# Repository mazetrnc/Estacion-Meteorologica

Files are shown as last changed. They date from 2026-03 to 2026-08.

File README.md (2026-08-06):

[Monitoreo de Estación Meteorológica en ThingSpeak](https://thingspeak.mathworks.com/channels/3108150) 

<h3>Funcionamiento de la Estación Meteorológica</h3>

La estación meteorológica desarrollada utiliza una **ESP32 como unidad central de procesamiento**, encargada de adquirir, procesar y transmitir los datos obtenidos por diversos sensores ambientales. El sistema integra varios módulos conectados principalmente mediante el protocolo **I2C**, así como comunicación **UART/RS485**, lo que permite medir múltiples variables meteorológicas y ambientales en tiempo real.

En primer lugar, el sensor **BME280** mide tres variables fundamentales del clima: **temperatura, humedad relativa y presión atmosférica**. A partir de la presión también se calcula la **altitud aproximada** utilizando una presión de referencia al nivel del mar. Estos datos son obtenidos a través del bus I2C y se almacenan en variables para su posterior procesamiento.



La calidad del aire se monitorea mediante el sensor **SGP30**, que proporciona estimaciones de **CO₂ equivalente (eCO₂)** y **compuestos orgánicos volátiles totales (TVOC)**. Para mejorar la precisión de las mediciones, el código calcula la **humedad absoluta** a partir de los datos del BME280 y la envía al SGP30 como parámetro de compensación ambiental.



La **radiación ultravioleta** se mide con el sensor **LTR390**, también conectado por I2C, el cual proporciona un valor de radiación UV que puede relacionarse con el **índice UV utilizado por organismos de salud**.



Para medir la **precipitación**, se utiliza un **sensor de lluvia con cubeta basculante**, que contabiliza los pulsos generados por cada basculación causada por la acumulación de agua. El código convierte estos pulsos en **milímetros de lluvia acumulada**, permitiendo conocer la precipitación en un periodo determinado.



La **velocidad del viento** se obtiene mediante un **anemómetro con salida RS485**, que transmite los datos usando el protocolo **Modbus RTU**. Debido a que la ESP32 trabaja con niveles TTL, se emplea un **módulo conversor MAX485** para adaptar la señal RS485 a comunicación serial. El código envía una solicitud Modbus al anemómetro, recibe la respuesta, verifica su integridad mediante **CRC16**, y finalmente convierte el valor recibido en **metros por segundo (m/s)**.




Una vez que la ESP32 realiza la lectura de todos los sensores integrados (aproximadamente cada **5 segundos**), procesa la información y la expone mediante una arquitectura de red dual que combina monitoreo local e IoT en la nube simultáneamente:

1. **Servidor Web Local en Tiempo Real (Modo AP):** La ESP32 crea un punto de acceso Wi-Fi propio (`SSID: EstacionMeteo`) donde aloja un **servidor web asíncrono (`ESPAsyncWebServer`)** en la IP `192.168.4.1`. La interfaz web (almacenada en `PROGMEM` / `pagina_web.h`) consulta automáticamente el endpoint `/datos` mediante peticiones `XMLHttpRequest` en segundo plano **cada 10 segundos**. Esto actualiza los indicadores, alertas y gráficos locales de forma instantánea sin requerir recargas de página ni depender de una conexión a Internet.

2. **Publicación Remota en la Nube (Modo STA - ThingSpeak):** De forma paralela y utilizando la misma interfaz de red (`WIFI_AP_STA`), la ESP32 se conecta como cliente a un router local con salida a Internet. **Cada 5 minutos (`POST_INTERVAL_MS = 300000`)**, el microcontrolador realiza una **petición HTTP GET** al servidor de **ThingSpeak** (`api.thingspeak.com`), mapeando las lecturas a los campos del canal:

* **Field 1:** Temperatura (°C)

* **Field 2:** Humedad (%)

* **Field 3:** Presión (hPa)

* **Field 4:** Velocidad del viento (m/s)

* **Field 5:** eCO₂ (ppm)

* **Field 6:** TVOC (ppb)

* **Field 7:** Precipitación / Tasa (mm/h)

* **Field 8:** Índice UV (OMS)

Ambos modos funcionan simultáneamente y de forma totalmente independiente: si la conexión Wi-Fi a Internet falla o no está disponible, el envío a ThingSpeak se omite temporalmente sin afectar la operación del servidor web local, el cual sigue sirviendo los datos en tiempo real de forma ininterrumpida.

En conjunto, esta estación meteorológica integra sensores ambientales de precisión, protocolos de comunicación industrial y de bus (I2C y RS485/Modbus RTU), servidor web embebido y conectividad IoT híbrida para crear un sistema robusto capaz de **monitorear condiciones climáticas en tiempo real de forma local y, al mismo tiempo, publicar los resultados en una plataforma en la nube para su almacenamiento histórico y análisis remoto**.

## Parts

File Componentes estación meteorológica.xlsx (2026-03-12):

Sensor Digital BME280 I2C - Termómetro, higrómetro, barómetro | https://ja-bots.com/producto/sensor-digital-bme280-i2c/ | 22000.00
Sensor de calidad del aire SGP30 | https://www.mercadolibre.com.co/sensor-calidad-de-aire-sgp30-tvoc-eco2-i2c-gysgp30/up/MCOU3815852079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 | 29500
ANEMÓMETRO O TRASMISOR DE VELOCIDAD DEL VIENTO RS485 | https://es.aliexpress.com/item/1005005707223060.html | 102240
Módulo Conversor RS485 a TTL Uart Max485 | https://ja-bots.com/producto/modulo-conversor-rs485-a-ttl-uart-max485/ | 6000.00
Módulo sensor de luz visible UV LTR390 | https://ja-bots.com/producto/modulo-sensor-de-luz-visible-uv-ltr390/ | 47000.00
Sensor de lluvia con cubeta basculante - I2C y UART | https://es.aliexpress.com/item/1005005624682669.html?scm_id=1007.40050.354490.0&scm-url=1007.40050.354490.0 | 114938
Total sin envios |  | 321678

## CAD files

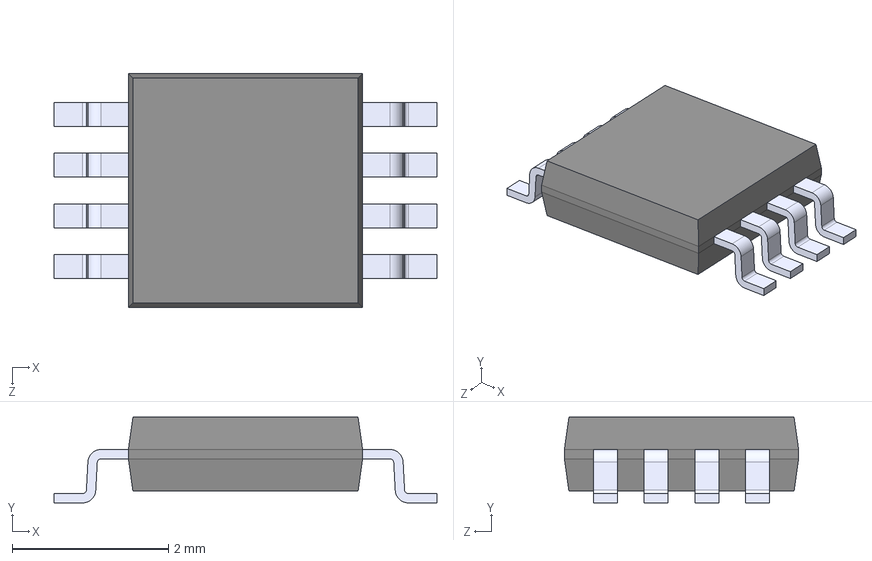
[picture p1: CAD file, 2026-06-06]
Estación metereológica/esquema_em/MAX485.step
4.91 x 1.10 x 3.00 mm

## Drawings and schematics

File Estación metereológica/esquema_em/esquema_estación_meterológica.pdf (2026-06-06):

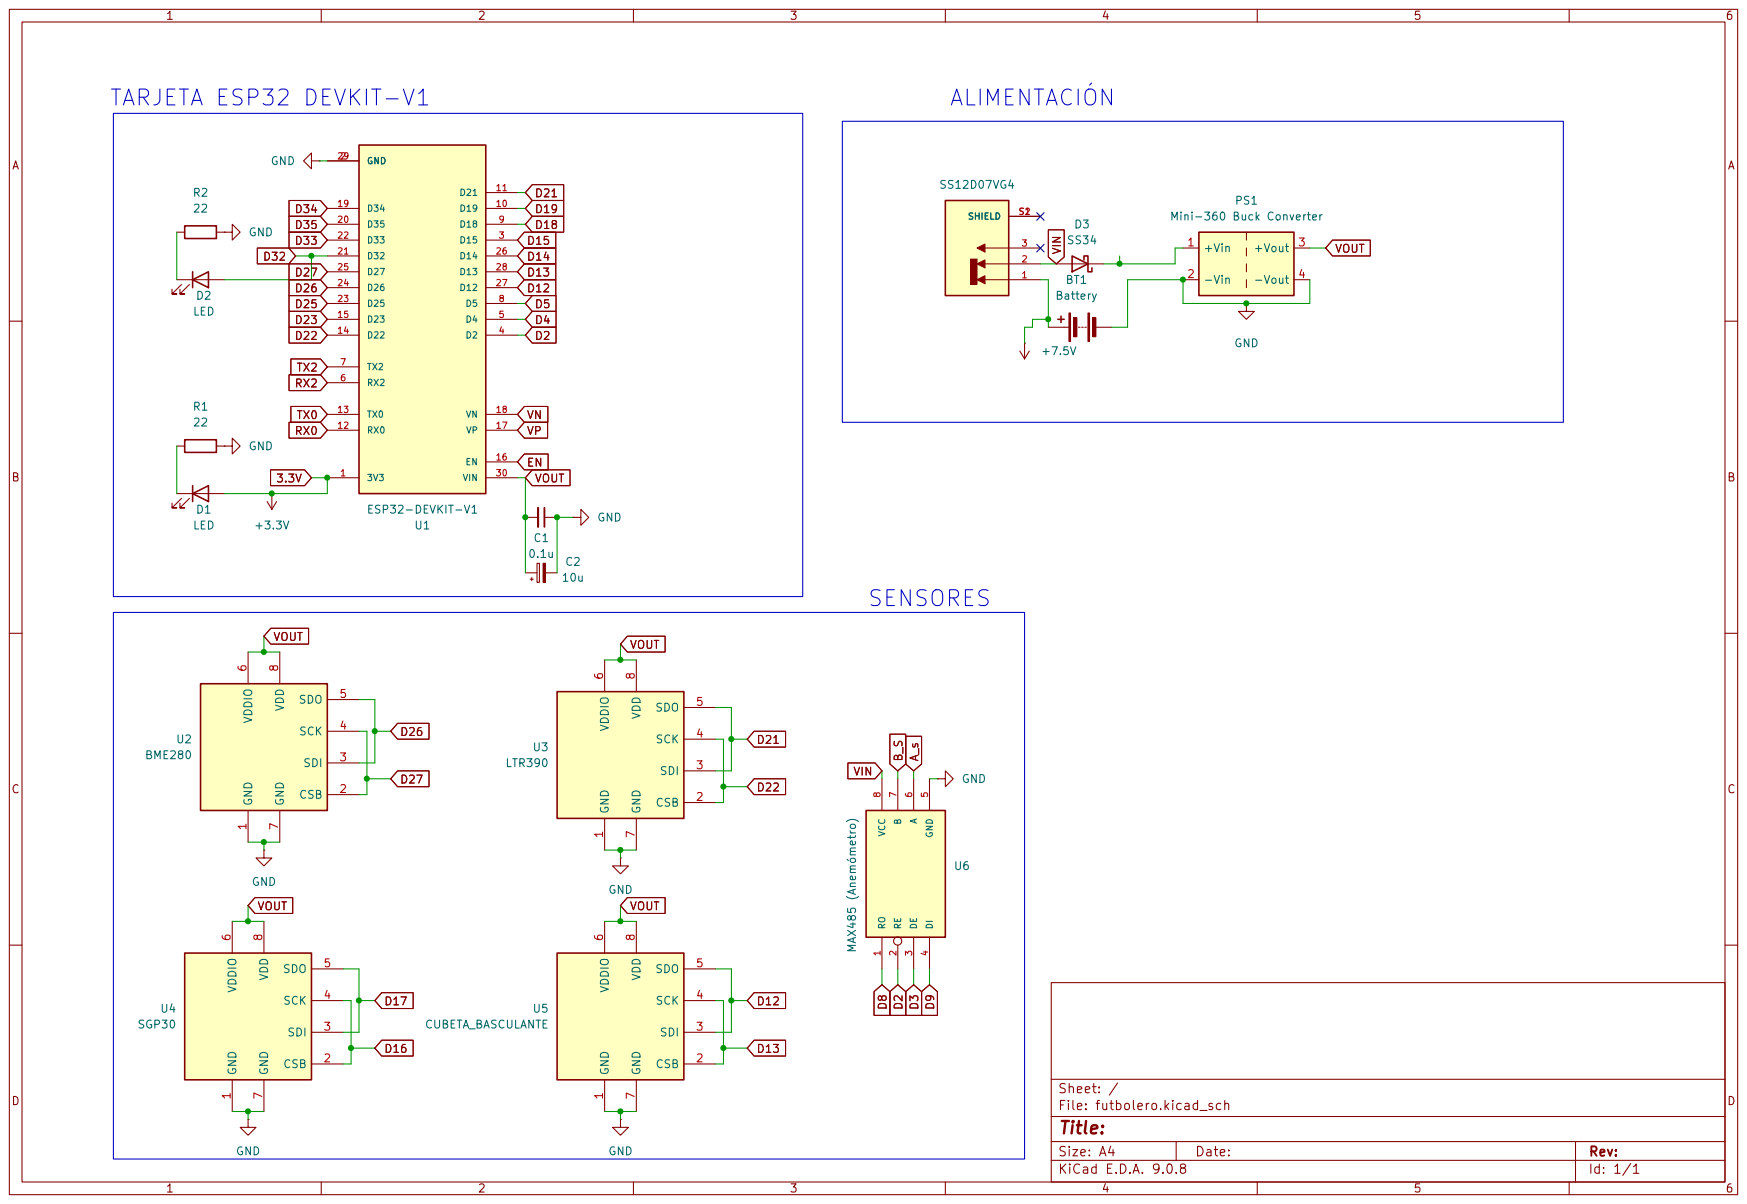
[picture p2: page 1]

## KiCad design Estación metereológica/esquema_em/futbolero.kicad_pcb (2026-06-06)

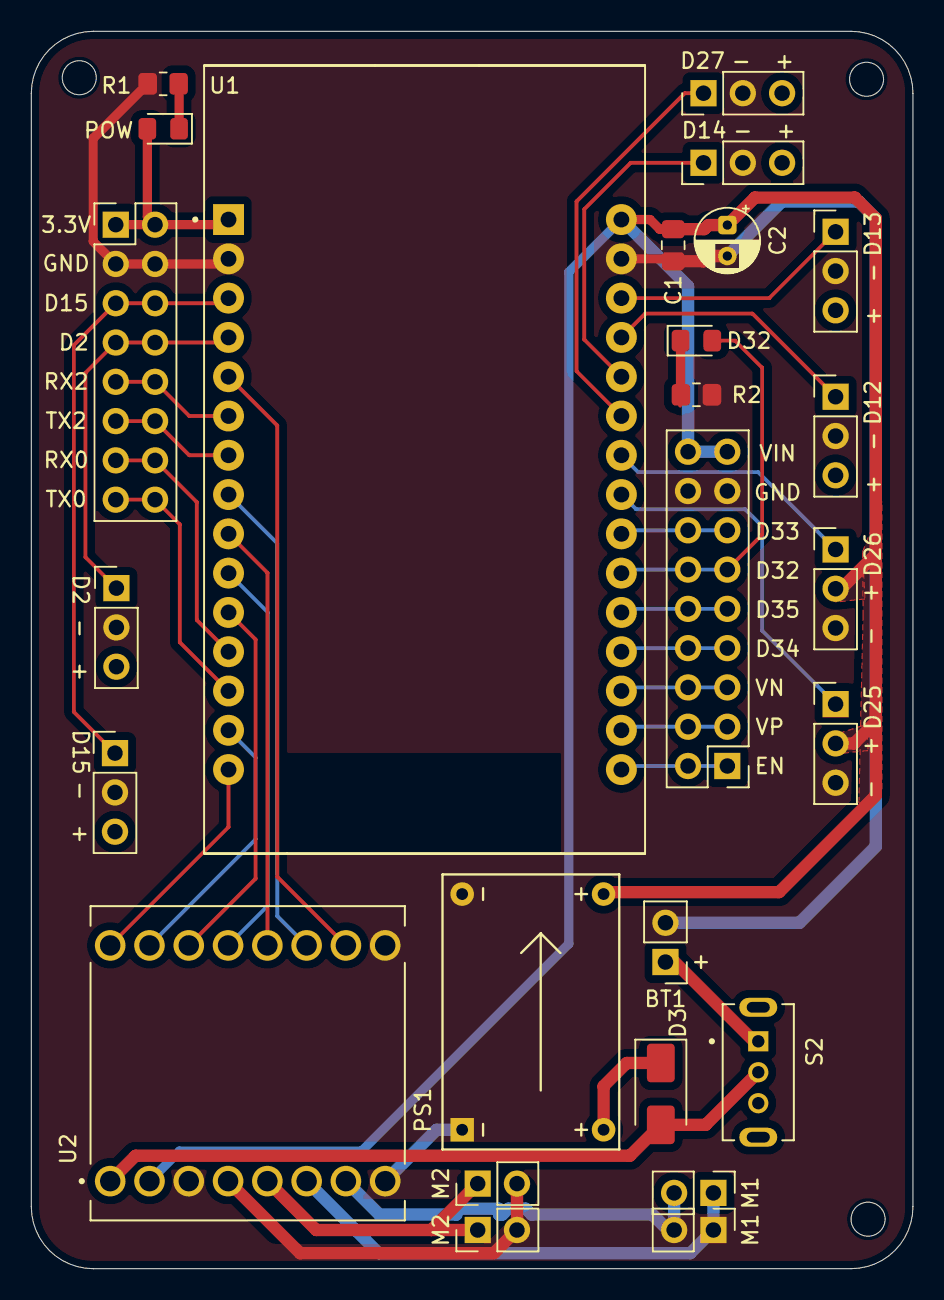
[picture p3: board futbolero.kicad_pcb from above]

Board: 2 copper layers, 57.0 x 80.0 mm, 26 parts (0 on the bottom side), 38 nets.

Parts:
BT1: Battery; PinHeader_1x02_P2.54mm_Vertical
C1: 0.1u; C_0805_2012Metric_Pad1.18x1.45mm_HandSolder
C2: 10u; CP_Radial_D4.0mm_P2.00mm
D3: SS34; D_SMA
D32: LED; LED_0805_2012Metric_Pad1.15x1.40mm_HandSolder
J1: Conn_02x08_Odd_Even; PinHeader_2x08_P2.54mm_Vertical
J2: Conn_02x09_Odd_Even; PinHeader_2x09_P2.54mm_Vertical
J3, J4, J5, J6, J7, J8, J9, J10: Conn_01x03; PinHeader_1x03_P2.54mm_Vertical
M1, M1#2, M2, M2#2: Motor_DC; PinHeader_1x02_P2.54mm_Vertical
POW: LED; LED_0805_2012Metric_Pad1.15x1.40mm_HandSolder
PS1: Mini-360 Buck Converter; Mini360_Module
R1, R2: 22; R_0805_2012Metric_Pad1.20x1.40mm_HandSolder
S2: SS12D07VG4; SW_SS12D07VG4
U1: ESP32-DEVKIT-V1; MODULE_ESP32_DEVKIT_V1
U2: TB6612FNG; MODULE_TB6612FNG

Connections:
3.3V: J1.1, J1.2, J3.3, J4.3, J5.3, J8.3, J9.3, J10.3, POW.2 (A), U1.1 (3V3)
+7.5V: BT1.1 (+), S2.1
D2: J1.7, J1.8, J4.1, U1.4 (D2)
D4: U1.5 (D4), U2.10 (PWMB)
D5: U1.8 (D5), U2.11 (BI2)
D12: J5.1, U1.27 (D12)
D13: J8.1, U1.28 (D13)
D14: J10.1, U1.26 (D14)
D15: J1.5, J1.6, J3.1, U1.3 (D15)
D18: U1.9 (D18), U2.12 (BI1)
D19: U1.10 (D19), U2.13 (STBY)
D21: U1.11 (D21), U2.14 (AI1)
D22: U1.14 (D22), U2.15 (AI2)
D23: U1.15 (D23), U2.16 (PWMA)
D25: J7.1, U1.23 (D25)
D26: J6.1, U1.24 (D26)
D27: J9.1, U1.25 (D27)
D32: D32.2 (A), J2.11, J2.12, U1.21 (D32)
D33: J2.13, J2.14, U1.22 (D33)
D34: J2.7, J2.8, U1.19 (D34)
D35: J2.9, J2.10, U1.20 (D35)
EN: J2.1, J2.2, U1.16 (EN)
GND: BT1.2 (-), C1.1, C2.2, J1.3, J1.4, J2.15, J2.16, J3.2, J4.2, J5.2, J6.3, J7.3, J8.2, J9.2, J10.2, PS1.2 (-Vin), PS1.4 (-Vout), R1.2, R2.2, U1.2 (GND), U1.29 (GND), U2.3 (GND), U2.8 (GND), U2.9 (GND)
unnamed: POW.1 (K), R1.1
unnamed: D32.1 (K), R2.1
unnamed: D3.1 (K), PS1.1 (+Vin)
unnamed: M1.1 (+), M1#2.1 (+), U2.6 (B02)
unnamed: M1.2 (-), M1#2.2 (-), U2.7 (B01)
unnamed: M2.1 (+), M2#2.1 (+), U2.5 (A02)
unnamed: M2.2 (-), M2#2.2 (-), U2.4 (A01)
RX0: J1.13, J1.14, U1.12 (RX0)
RX2: J1.9, J1.10, U1.6 (RX2)
TX0: J1.15, J1.16, U1.13 (TX0)
TX2: J1.11, J1.12, U1.7 (TX2)
VIN: D3.2 (A), S2.2, U2.1 (VM)
VN: J2.5, J2.6, U1.18 (VN)
VOUT: C1.2, C2.1, J2.17, J2.18, J6.2, J7.2, PS1.3 (+Vout), U1.30 (VIN), U2.2 (VCC)
VP: J2.3, J2.4, U1.17 (VP)

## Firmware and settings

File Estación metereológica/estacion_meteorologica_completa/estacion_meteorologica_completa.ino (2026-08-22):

// ============================================================
//  ESTACIÓN METEOROLÓGICA — ESP32 AP+STA + WEB LOCAL + THINGSPEAK
//  Sensores: BME280 | LTR390 | SGP30 | Pluviómetro Basculante | Anemómetro RS485
//
//  MODO WiFi: AP + STA simultáneo
//    - AP propio (siempre activo, sin necesidad de internet):
//        SSID: EstacionMeteo
//        Pass: estacion123
//        IP:   192.168.4.1  → abrir en navegador para ver la web local
//    - STA (cliente, para subir datos a ThingSpeak si hay internet):
//        SSID:
//        Pass:
//
//  Si no hay conexión a internet (STA falla), la página web local
//  sigue funcionando con normalidad vía el AP. El envío a ThingSpeak
//  simplemente se omite y se reintenta en el siguiente ciclo.
//
//  Librerías (Library Manager):
//    - Adafruit BME280 Library
//    - Adafruit LTR390 Library
//    - Adafruit SGP30 Library
//    - Adafruit Unified Sensor
//    - ESPAsyncWebServer  (por "ESP32Async" — NO el original de me-no-dev,
//                          que está archivado y da el error de assert
//                          "tcp_alloc ... Required to lock TCPIP core
//                          functionality" en el core ESP32 3.x / IDF 5.x)
//    - AsyncTCP           (por "ESP32Async" — misma organización que la
//                          librería anterior, deben instalarse juntas)
//    - ArduinoJson        (by Benoit Blanchon)
//    - ModbusMaster       (by Doc Walker)
//
//  INSTALACIÓN CORRECTA (Library Manager de Arduino IDE):
//    1. Si ya tienes instaladas versiones viejas de ESPAsyncWebServer o
//       AsyncTCP, elimínalas primero (Administrador de Bibliotecas → busca
//       el nombre → "Eliminar" o borra la carpeta en Documentos/Arduino/libraries).
//    2. Busca "ESPAsyncWebServer" y en la lista de autores elige la
//       mantenida por "ESP32Async" (no la de "ESP32Async Team" antigua
//       ni la original archivada).
//    3. Busca "AsyncTCP" e instala también la de "ESP32Async".
//    4. Ambas deben quedar de la MISMA organización/fork para ser
//       compatibles entre sí.
//
//  ESTRUCTURA DE ARCHIVOS (misma carpeta):
//    estacion_meteorologica_completa.ino   ← este archivo
//    pagina_web.h                          ← HTML/CSS/JS de la web
//
//  PINES:
//    Bus I2C 0 → Wire  (SDA=15, SCL=27) → BME280
//    Bus I2C 1 → Wire1 (SDA=32, SCL=33) → LTR390 + SGP30
//    Digital   → Pin 14 (INPUT_PULLUP)  → Pluviómetro basculante
//    UART2     → RX=16, TX=17, DE=25, RE=26 → Anemómetro RS485 Modbus RTU
//
//  CAMPOS THINGSPEAK ENVIADOS:
//    field1 = Temperatura       (°C)
//    field2 = Humedad           (%)
//    field3 = Presión           (hPa)
//    field4 = Velocidad viento  (m/s)
//    field5 = eCO2              (ppm)
//    field6 = TVOC              (ppb)
//    field7 = Precipitación     (~1 H equiv., mm)
//    field8 = Indice UV (OMS)
// ============================================================

#include <Wire.h>
#include <WiFi.h>
#include <WiFiClient.h>
#include <ESPAsyncWebServer.h>
#include <ArduinoJson.h>
#include <ModbusMaster.h>

// El HTML está en un .h separado para evitar que el
// preprocesador de Arduino confunda JS con código C++
#include "pagina_web.h"

// ── BME280 ────────────────────────────────────────────────
#include <Adafruit_Sensor.h>
#include <Adafruit_BME280.h>
#define SDA_BME  15
#define SCL_BME  27
#define SEALEVELPRESSURE_HPA (1013.25)
Adafruit_BME280 bme;

// ── LTR390 ───────────────────────────────────────────────
#include <Adafruit_LTR390.h>
#define SDA_I2C1 32
#define SCL_I2C1 33
Adafruit_LTR390 ltr = Adafruit_LTR390();

// ── SGP30 ────────────────────────────────────────────────
#include "Adafruit_SGP30.h"
Adafruit_SGP30 sgp;
int contadorCalentamiento = 0;

// ── PLUVIÓMETRO BASCULANTE ────────────────────────────────
const int        pinPluviometro    = 14;
volatile int     conteoPulsos      = 0;
unsigned long    ultimoTiempoRebote = 0;
const int        tiempoAntiRebote  = 200;
const float      MM_POR_PULSO      = 0.2794;
unsigned long    tiempoInicioMs    = 0;

// ── ANEMÓMETRO RS485 MODBUS RTU ───────────────────────────
#define RX_PIN_ANEM   16
#define TX_PIN_ANEM   17
#define DE_PIN_ANEM   25
#define RE_PIN_ANEM   26
#define MODBUS_ADDRESS  3

HardwareSerial RS485Serial(2);
ModbusMaster anemometro;

// ── DATOS GLOBALES (compartidos con el servidor web) ──────
struct DatosEstacion {
  float         temperatura;
  float         presion;
  float         altitud;
  float         humedad;
  float         lux;
  float         uvi;
  uint32_t      uvRaw;
  uint16_t      eco2;
  uint16_t      tvoc;
  float         mmAcumulados;
  float         lluviaPorHora;
  int           pulsos;
  float         horasOperacion;
  bool          sgpCalentando;
  float         vientoMs;
  float         vientoKmh;
  float         vientoNudos;
  bool          vientoOK;
} datos;

// ── TEMPORIZACIÓN ─────────────────────────────────────────
unsigned long ultimaLectura = 0;
const unsigned long INTERVALO_MS = 5000;        // lectura/serial cada 5 s
unsigned long lastPostMs = 0;
const unsigned long POST_INTERVAL_MS = 300000;  // ThingSpeak cada 5 min

// ── ACCESS POINT (siempre activo) ─────────────────────────
const char* AP_SSID = "EstacionMeteo";
const char* AP_PASS = "estacion123";

// ── STA / WiFi (para internet, si está disponible) ────────
const char* WIFI_SSID     = "Galaxy A17";
const char* WIFI_PASSWORD = "12345678";
const unsigned long WIFI_CONNECT_TIMEOUT = 15000;

// ── THINGSPEAK ─────────────────────────────────────────────
const char* THINGSPEAK_HOST = "api.thingspeak.com";
const int   THINGSPEAK_PORT = 80;
String      WRITE_API_KEY   = "G3HHRN4N0G8XNWBY";

WiFiClient client;

// ── SERVIDOR WEB ASÍNCRONO (vía AP) ───────────────────────
AsyncWebServer server(80);


// ─────────────────────────────────────────────────────────
//  ISR: Pluviómetro
// ─────────────────────────────────────────────────────────
void IRAM_ATTR contarVueltaCubeta() {
  unsigned long t = millis();
  if (t - ultimoTiempoRebote > (unsigned long)tiempoAntiRebote) {
    conteoPulsos++;
    ultimoTiempoRebote = t;
  }
}

// ─────────────────────────────────────────────────────────
//  Callbacks RS485 para controlar DE y RE del anemómetro
// ─────────────────────────────────────────────────────────
void preTransmissionAnem() {
  digitalWrite(RE_PIN_ANEM, HIGH);
  digitalWrite(DE_PIN_ANEM, HIGH);
}

void postTransmissionAnem() {
  digitalWrite(DE_PIN_ANEM, LOW);
  digitalWrite(RE_PIN_ANEM, LOW);
}

// ─────────────────────────────────────────────────────────
//  WiFi STA — intenta conectar sin bloquear el AP
// ─────────────────────────────────────────────────────────
void connectToWiFiSTA() {
  Serial.print("[WiFi STA] Conectando a: ");
  Serial.println(WIFI_SSID);
  WiFi.begin(WIFI_SSID, WIFI_PASSWORD);
  unsigned long start = millis();
  while (WiFi.status() != WL_CONNECTED && (millis() - start) < WIFI_CONNECT_TIMEOUT) {
    Serial.print(".");
    delay(500);
  }
  Serial.println();
  if (WiFi.status() == WL_CONNECTED) {
    Serial.print("[WiFi STA] Conectado. IP: ");
    Serial.println(WiFi.localIP());
  } else {
    Serial.println("[WiFi STA] Sin conexion a internet. Solo modo local (AP).");
  }
}

// ─────────────────────────────────────────────────────────
//  ThingSpeak — campos enviados
//    field1=temp  field2=hum   field3=pre   field4=vel_viento
//    field5=co2   field6=tvoc  field7=pluvi field8=uvi
// ─────────────────────────────────────────────────────────
bool sendToThingSpeak(float temp, float hum, float pre, float vel_vie,
                      float co2,  float tvoc,
                      float pluvi, float uvi) {

  String url = "/update?api_key=" + WRITE_API_KEY +
               "&field1=" + String(temp, 2) +
               "&field2=" + String(hum,  2) +
               "&field3=" + String(pre,  2) +
               "&field4=" + String(vel_vie, 1) +
               "&field5=" + String(co2,  1) +
               "&field6=" + String(tvoc, 1) +
               "&field7=" + String(pluvi, 4) +
               "&field8=" + String(uvi,  2);

  if (!client.connect(THINGSPEAK_HOST, THINGSPEAK_PORT)) {
    Serial.println("[HTTP] Error: No se pudo abrir conexión TCP.");
    return false;
  }

  String request = String("GET ") + url + " HTTP/1.1\r\n" +
                   "Host: " + THINGSPEAK_HOST + "\r\n" +
                   "Connection: close\r\n\r\n";
  client.print(request);

  unsigned long startWait = millis();
  while (!client.available() && (millis() - startWait) < 5000) delay(10);

  if (!client.available()) {
    Serial.println("[HTTP] Error: Sin respuesta del servidor.");
    client.stop();
    return false;
  }

  String response;
  while (client.available()) response += client.readStringUntil('\n') + "\n";
  client.stop();

  int lastNL = response.lastIndexOf('\n', response.length() - 2);
  String body = response.substring(lastNL + 1);
  body.trim();

  if (body == "0") {
    Serial.println("[ThingSpeak] Publicación rechazada (código 0). Verifica intervalo y API Key.");
    return false;
  }
  Serial.print("[ThingSpeak] Publicación exitosa. Entry ID: ");
  Serial.println(body);
  return true;
}


// ─────────────────────────────────────────────────────────
//  SETUP
// ─────────────────────────────────────────────────────────
void setup() {
  Serial.begin(115200);
  while (!Serial) delay(10);
  Serial.println("\n==============================================");
  Serial.println("   ESTACION METEOROLOGICA - AP+STA / WEB / THINGSPEAK");
  Serial.println("==============================================\n");

  // ── Bus I2C 0: BME280 ─────────────────────────────────
  Wire.begin(SDA_BME, SCL_BME);
  if (!bme.begin(0x76, &Wire)) {
    Serial.println("[ERROR] BME280 no encontrado en SDA=15 SCL=27.");
    while (1);
  }
  Serial.println("[OK] BME280 listo.");

  // ── Bus I2C 1: LTR390 + SGP30 ────────────────────────
  Wire1.begin(SDA_I2C1, SCL_I2C1);

  if (!ltr.begin(&Wire1)) {
    Serial.println("[ERROR] LTR390 no encontrado en SDA=32 SCL=33.");
    while (1);
  }
  ltr.setGain(LTR390_GAIN_18);
  ltr.setResolution(LTR390_RESOLUTION_16BIT);
  Serial.println("[OK] LTR390 listo.");

  if (!sgp.begin(&Wire1)) {
    Serial.println("[ERROR] SGP30 no encontrado en SDA=32 SCL=33.");
    while (1);
  }
  Serial.println("[OK] SGP30 listo.");

  // ── Pluviómetro ───────────────────────────────────────
  pinMode(pinPluviometro, INPUT_PULLUP);
  attachInterrupt(digitalPinToInterrupt(pinPluviometro),
                  contarVueltaCubeta, FALLING);
  tiempoInicioMs = millis();
  Serial.println("[OK] Pluviometro listo en Pin 14.");

  // ── Anemómetro RS485 Modbus RTU ───────────────────────
  pinMode(DE_PIN_ANEM, OUTPUT);
  pinMode(RE_PIN_ANEM, OUTPUT);
  digitalWrite(DE_PIN_ANEM, LOW);
  digitalWrite(RE_PIN_ANEM, LOW);

  RS485Serial.begin(9600, SERIAL_8N1, RX_PIN_ANEM, TX_PIN_ANEM);
  delay(100);

  anemometro.begin(MODBUS_ADDRESS, RS485Serial);
  anemometro.preTransmission(preTransmissionAnem);
  anemometro.postTransmission(postTransmissionAnem);
  Serial.println("[OK] Anemometro RS485 listo (RX=16, TX=17, DE=25, RE=26).");

  // ── WiFi: AP + STA simultáneo ─────────────────────────
  WiFi.mode(WIFI_AP_STA);
  WiFi.softAP(AP_SSID, AP_PASS);
  IPAddress ip = WiFi.softAPIP();
  Serial.print("[WiFi AP] Activo  SSID: ");
  Serial.println(AP_SSID);
  Serial.print("[WiFi AP] Contrasena: ");
  Serial.println(AP_PASS);
  Serial.print("[WiFi AP] Pagina local: http://");
  Serial.println(ip);

  // Intenta conectar a internet, pero el AP sigue activo igual
  connectToWiFiSTA();

  // ── Rutas del servidor web local (vía AP) ─────────────
  server.on("/", HTTP_GET, [](AsyncWebServerRequest* req) {
    req->send_P(200, "text/html", HTML_PAGE);
  });

  server.on("/datos", HTTP_GET, [](AsyncWebServerRequest* req) {
    StaticJsonDocument<512> doc;
    doc["temperatura"]    = datos.temperatura;
    doc["presion"]        = datos.presion;
    doc["altitud"]        = datos.altitud;
    doc["humedad"]        = datos.humedad;
    doc["lux"]            = datos.lux;
    doc["uvi"]            = datos.uvi;
    doc["uvRaw"]          = datos.uvRaw;
    doc["eco2"]           = datos.eco2;
    doc["tvoc"]           = datos.tvoc;
    doc["mmAcumulados"]   = datos.mmAcumulados;
    doc["lluviaPorHora"]  = datos.lluviaPorHora;
    doc["pulsos"]         = datos.pulsos;
    doc["horasOperacion"] = datos.horasOperacion;
    doc["sgpCalentando"]  = datos.sgpCalentando;
    doc["vientoMs"]       = datos.vientoMs;
    doc["vientoKmh"]      = datos.vientoKmh;
    doc["vientoNudos"]    = datos.vientoNudos;
    doc["vientoOK"]       = datos.vientoOK;
    doc["uptime"]         = millis() / 1000UL;
    doc["internet"]       = (WiFi.status() == WL_CONNECTED);

    String json;
    serializeJson(doc, json);
    req->send(200, "application/json", json);
  });

  server.onNotFound([](AsyncWebServerRequest* req) {
    req->send(404, "text/plain", "no encontrado");
  });

  server.begin();
  Serial.println("[OK] Servidor web local iniciado.\n");

  // ── Lectura inicial para no servir datos vacíos ───────
  datos.temperatura   = bme.readTemperature();
  datos.presion       = bme.readPressure() / 100.0F;
  datos.altitud       = bme.readAltitude(SEALEVELPRESSURE_HPA);
  datos.humedad       = bme.readHumidity();
  sgp.setHumidity(getAbsoluteHumidity(datos.temperatura, datos.humedad));
  datos.lux           = 0;
  datos.uvi           = 0;
  datos.uvRaw         = 0;
  datos.eco2          = 400;
  datos.tvoc          = 0;
  datos.mmAcumulados  = 0;
  datos.lluviaPorHora = 0;
  datos.pulsos        = 0;
  datos.horasOperacion = 0;
  datos.sgpCalentando = true;
  datos.vientoMs      = 0;
  datos.vientoKmh     = 0;
  datos.vientoNudos   = 0;
  datos.vientoOK      = false;

  ultimaLectura = millis();
  lastPostMs    = millis() - POST_INTERVAL_MS; // fuerza primer envío si hay internet

  Serial.println("==============================================");
  Serial.println("   Todo listo. Iniciando ciclo de lectura.");
  Serial.println("==============================================\n");
}


// ─────────────────────────────────────────────────────────
//  Compensación de humedad absoluta para el SGP30
//  Fórmula de aproximación (Sensirion SGP30 Driver Integration,
//  cap. 3.15) a partir de temperatura y humedad relativa del BME280.
//  Devuelve el valor en formato fijo mg/m^3 que espera setHumidity().
// ─────────────────────────────────────────────────────────
uint32_t getAbsoluteHumidity(float temperatura, float humedadRelativa) {
  const float humedadAbsoluta = 216.7f *
      ((humedadRelativa / 100.0f) * 6.112f *
       exp((17.62f * temperatura) / (243.12f + temperatura)) /
       (273.15f + temperatura)); // g/m^3
  const uint32_t humedadAbsolutaEscalada =
      static_cast<uint32_t>(1000.0f * humedadAbsoluta); // mg/m^3
  return humedadAbsolutaEscalada;
}

// ─────────────────────────────────────────────────────────
//  LOOP
// ─────────────────────────────────────────────────────────
unsigned long ultimaLecturaSGP = 0;

void loop() {
  unsigned long ahora = millis();

  // SGP30: leer exactamente cada 1000 ms (requisito del sensor)
  if (ahora - ultimaLecturaSGP >= 1000) {
    ultimaLecturaSGP = ahora;

    // Compensación de humedad absoluta usando la última
    // lectura disponible del BME280 (temperatura y humedad relativa)
    sgp.setHumidity(getAbsoluteHumidity(datos.temperatura, datos.humedad));

    if (!sgp.IAQmeasure()) {
      Serial.println("[SGP30] Error de lectura.");
    }
  }

  // Lecturas completas cada INTERVALO_MS (5 s)
  if (ahora - ultimaLectura >= INTERVALO_MS) {
    ultimaLectura = ahora;

    // ── BME280 ──────────────────────────────────────────
    datos.temperatura = bme.readTemperature();
    datos.presion     = bme.readPressure() / 100.0F;
    datos.altitud     = bme.readAltitude(SEALEVELPRESSURE_HPA);
    datos.humedad     = bme.readHumidity();

    // ── LTR390 ──────────────────────────────────────────
    ltr.setMode(LTR390_MODE_UVS);
    delay(100);
    if (ltr.newDataAvailable()) {
      datos.uvRaw = ltr.readUVS();
      datos.uvi   = (float)datos.uvRaw / 2300.0;
    }
    ltr.setMode(LTR390_MODE_ALS);
    delay(100);
    if (ltr.newDataAvailable()) {
      uint32_t als = ltr.readALS();
      datos.lux    = als * 0.6;
    }

    // ── SGP30 ────────────────────────────────────────────
    datos.eco2 = sgp.eCO2;
    datos.tvoc = sgp.TVOC;
    if (contadorCalentamiento < 15) {
      contadorCalentamiento++;
      datos.sgpCalentando = true;
    } else {
      datos.sgpCalentando = false;
    }

    // ── Pluviómetro ──────────────────────────────────────
    datos.horasOperacion = (float)(millis() - tiempoInicioMs) / 3600000.0;
    datos.mmAcumulados   = conteoPulsos * MM_POR_PULSO;
    datos.pulsos         = conteoPulsos;
    datos.lluviaPorHora  = (datos.horasOperacion > 0.0)
                           ? (datos.mmAcumulados / datos.horasOperacion)
                           : 0.0;

    // ── Anemómetro RS485 ──────────────────────────────────
    uint8_t resultAnem = anemometro.readHoldingRegisters(0x0000, 1);
    if (resultAnem == anemometro.ku8MBSuccess) {
      uint16_t raw       = anemometro.getResponseBuffer(0);
      datos.vientoMs    = raw / 10.0;
      datos.vientoKmh   = datos.vientoMs * 3.6;
      datos.vientoNudos = datos.vientoMs * 1.94384;
      datos.vientoOK    = true;
    } else {
      datos.vientoOK = false;
    }

    // ── Serial ───────────────────────────────────────────
    Serial.println("----------------------------------------------");
    Serial.printf("[PLUVIOMETRO] Pulsos: %d | %.4f mm | %.4f mm/h\n",
                  conteoPulsos, datos.mmAcumulados, datos.lluviaPorHora);
    Serial.printf("[BME280]  T: %.2f C | P: %.2f hPa | H: %.2f %%\n",
                  datos.temperatura, datos.presion, datos.humedad);
    Serial.printf("[LTR390]  Lux: %.1f | UVI: %.2f\n",
                  datos.lux, datos.uvi);
    Serial.printf("[SGP30]   eCO2: %d ppm | TVOC: %d ppb%s\n",
                  datos.eco2, datos.tvoc,
                  datos.sgpCalentando ? " [calentando]" : "");
    if (datos.vientoOK) {
      Serial.printf("[VIENTO]  %.1f m/s | %.1f km/h | %.1f nudos\n",
                    datos.vientoMs, datos.vientoKmh, datos.vientoNudos);
    } else {
      Serial.printf("[VIENTO]  [ERROR] Codigo Modbus: 0x%02X\n", resultAnem);
    }
    Serial.printf("[WiFi]    AP activo | STA: %s\n",
                  (WiFi.status() == WL_CONNECTED) ? "conectado (internet OK)" : "sin conexion");
    Serial.println("----------------------------------------------\n");

    // ════════════════════════════════════════════════════
    //  THINGSPEAK — solo si hay internet, cada POST_INTERVAL_MS
    // ════════════════════════════════════════════════════
    if (millis() - lastPostMs >= POST_INTERVAL_MS) {

      if (WiFi.status() != WL_CONNECTED) {
        Serial.println("[WiFi STA] Desconectado. Reintentando...");
        connectToWiFiSTA();
      }

      if (WiFi.status() == WL_CONNECTED) {
        Serial.println("[ThingSpeak] Enviando datos...");
        bool ok = sendToThingSpeak(datos.temperatura, datos.humedad, datos.presion,
                                    datos.vientoMs, (float)datos.eco2, (float)datos.tvoc,
                                    datos.lluviaPorHora, datos.uvi);
        if (!ok) Serial.println("[Main] Fallo el envio a ThingSpeak. Se reintentara despues.");
      } else {
        Serial.println("[Main] Sin internet. Solo modo local (AP). No se envia a ThingSpeak.");
      }

      lastPostMs = millis();
    }
  }

  // Sin delay() — el loop corre libre, AsyncWebServer no se bloquea
}

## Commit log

2026-03-12 Enhance README with weather station functionality details
    Added detailed description of the weather station functionality, including sensor integration and data transmission to ThingSpeak.
2026-03-12 Enhance README with weather station functionality details
    Added detailed explanation of the weather station's functionality, including sensor descriptions and data transmission methods.
2026-08-06 Enhance README with ESP32 network architecture details
    Added detailed explanation of the ESP32's dual network architecture for sensor data processing and cloud publishing.
2026-08-06 Enhance README with ESP32 sensor and server details
    Added details about the ESP32's sensor reading process and local web server functionality.
2026-08-22 Replace AsyncWebServer with WebServer
    [estacion_meteorologica_completa.ino]
2026-08-22 Refactor web server to use AsyncWebServer
    Replaced WebServer with AsyncWebServer for improved performance and updated server handling methods.
    [estacion_meteorologica_completa.ino]
